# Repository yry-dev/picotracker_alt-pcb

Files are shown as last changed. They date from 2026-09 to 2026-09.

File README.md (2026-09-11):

# Picotracker Alt-PCB

~~**Do not fabricate! There could be a major mistake around MIDI!!**~~

**[Alex fixed it!](https://github.com/ijnekenamay/picotracker_alt-pcb/pull/2) We should be able to go ahead with production now.**

This project is about [democloid picoTracker's](https://github.com/democloid/picoTracker/) alternative PCB.
Inexpensive handheld devices can be built to run LittleGPTracker(a.k.a piggytracker).
It basically follows the original DIY version, with a few modifications of my own. They are described below.

[You can see it in motion here.](https://www.instagram.com/p/C2BvngaruZN/?utm_source=ig_web_copy_link&igsh=MzRlODBiNWFlZA==)



## Feature

- The two PCBs act as an enclosure by sandwiching the components together.
- I wanted a module for the charging function and plenty of memory, so I went with the [Pimoroni Pico LiPo](https://shop.pimoroni.com/products/pimoroni-pico-lipo).
- I wanted a micro-speaker like the DirtywaveM8, so I added one... and a Class D amplifier module.
- A speaker kill switch has been added.
- This also uses Kailh Choc V1 for the keycaps because of my personal taste.
- You can change any specification by yourself if you have access to Kicad.
- [See image for values of components around MIDI.](https://raw.githubusercontent.com/ijnekenamay/picotracker_alt-pcb/main/images/MIDI_resistor_value.jpg)
- I designed a back panel that could be output with a 3D printer because I felt the microspeaker needed box resonance. Also, if you would like to try it, please see the STL data. Feedback is welcome.
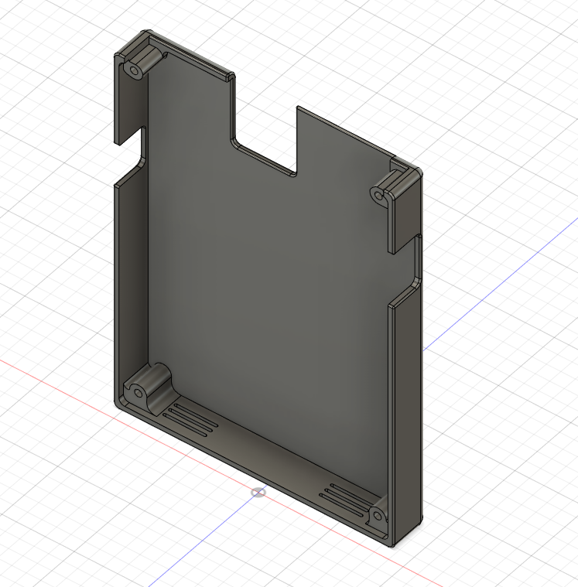
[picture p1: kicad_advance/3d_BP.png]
- 

## BOM

| Value | Qty | Avg unit price¹ | Mouser | DigiKey | Notes |
| --- | --- | --- | --- | --- | --- |
| Pimoroni Pico LiPo 16MB | 1 | ~$8–16 | — | — | [Pimoroni](https://shop.pimoroni.com/products/pimoroni-pico-lipo) (~$15.95, [PiShop US](https://www.pishop.us/product/pimoroni-pico-lipo-16mb/)) · [JP](https://akizukidenshi.com/catalog/g/g116997/). Equivalent: [Waveshare RP2040-Plus 16MB](https://www.amazon.com/Waveshare-RP2040-Plus-High-Performance-Microcontroller-Compatible/dp/B09KZKKWJT) ([Waveshare](https://www.waveshare.com/rp2040-plus.htm)), ~$8 — Pico-pinout, USB-C, onboard LiPo charge, 16MB (use the **no-header/castellated** version). |
| ILI9341 3.2" display | 1 | ~$12–18 | — | — | [AliExpress](https://www.aliexpress.us/item/3256802819098352.html). Equivalents: generic 3.2" ILI9341 SPI 320×240 on [Amazon](https://www.amazon.com/ALMOCN-ILI9341-Display-320x240-Screen/dp/B0C88S6FK7) (ALMOCN/Hosyond/ACEIRMC, ~$15) — **verify the 8-pin SPI header order matches J7**. Tayda has only a [2.8" ILI9341](https://www.taydaelectronics.com/2-8-inch-spi-display-screen-tft-with-touch-ili9341.html) (smaller). Mouser/DigiKey carry ILI9341 breakouts (Adafruit/Newhaven) but with different pinouts — **not drop-in**. |
| GY-PCM5102 DAC module | 1 | — | — | — | [AliExpress](https://www.aliexpress.us/item/3256802711963831.html) |
| Adafruit Micro SD SPI/SDIO Breakout | 1 | — | — | — | [Adafruit](https://www.adafruit.com/product/4682) |
| Kailh Choc V1 key switch | 9 | — | — | — | specialty (mechanical-keyboard vendors) |
| keycaps (Kailh Choc) | 9 | — | — | — | specialty |
| MAX98306 class-D amp module | 1 | — | — | — | [AliExpress](https://ja.aliexpress.com/item/1005004990814956.html) (Adafruit #987) |
| Micro speaker | 2 | — | — | — | [Akizuki](https://akizukidenshi.com/catalog/g/gP-12494/) |
| DPDT slide switch (through-hole) | 1 | ~$0.84 | [JS202011AQN](https://www.mouser.com/c/?q=JS202011AQN) | [JS202011AQN](https://www.digikey.com/en/products/detail/c-k/JS202011AQN/1640096) | J9 (KILL_SWITCH); C&K JS202011AQN, right-angle. Generic SS-22 / MSK22D18G2 (LCSC C2906279, ~$0.07) also fits. GND on center pins. |
| PJ-311 3.5mm stereo jack | 2 | varies | — | — | MIDI in/out (J1, J2). Generic PJ-311/PJ-320 import — no footprint-compatible Mouser/DigiKey catalog part. |
| 1N4148 | 1 | ~$0.10 | [1N4148](https://www.mouser.com/c/?q=1N4148) | [1N4148](https://www.digikey.com/en/products/result?keywords=1N4148) | D1; DO-35 axial |
| 47R | 2 | ~$0.11 | [CFR-25JB-52-47R](https://www.mouser.com/c/?q=CFR-25JB-52-47R) | [CFR-25JB-52-47R](https://www.digikey.com/en/products/result?keywords=CFR-25JB-52-47R) | axial 1/4W (DIN0207, 7.62mm) |
| 220R | 1 | ~$0.10 | [CFR-25JB-52-220R](https://www.mouser.com/c/?q=CFR-25JB-52-220R) | [CFR-25JB-52-220R](https://www.digikey.com/en/products/result?keywords=CFR-25JB-52-220R) | axial 1/4W (DIN0207, 7.62mm) |
| 470R | 1 | ~$0.11 | [CFR-25JB-52-470R](https://www.mouser.com/c/?q=CFR-25JB-52-470R) | [CFR-25JB-52-470R](https://www.digikey.com/en/products/result?keywords=CFR-25JB-52-470R) | axial 1/4W (DIN0207, 7.62mm) |
| 10k | 1 | ~$0.10 | [CFR-25JB-52-10K](https://www.mouser.com/c/?q=CFR-25JB-52-10K) | [CFR-25JB-52-10K](https://www.digikey.com/en/products/result?keywords=CFR-25JB-52-10K) | axial 1/4W (DIN0207, 7.62mm) |
| 6N138 | 1 | ~$0.83 | [6N138](https://www.mouser.com/c/?q=6N138) | [6N138](https://www.digikey.com/en/products/result?keywords=6N138) | U2; DIP-8 optocoupler |
| LiPo battery | 1 | — | — | — | 1200mAh (author's choice) — hobby battery vendors |
| Pin headers / standoffs / screws / nuts | * | — | [headers](https://www.mouser.com/c/?q=2.54mm+pin+header) | [headers](https://www.digikey.com/en/products/result?keywords=2.54mm+pin+header) | See note below on short headers vs sockets |

¹ **Avg unit price** — indicative qty-1 price in USD, from Mouser (the DPDT switch is averaged with DigiKey). Modules are priced at their linked vendors (they aren't stocked by Mouser/DigiKey). Most distributor cells are keyword/site searches — pick the exact package/stock on the results page; the DPDT switch uses direct product links (Mouser and DigiKey). Stock and prices change, so confirm at the link before ordering.

It is recommended to use short pin headers and to solder directly without using sockets. At the very least, the effective depth of the 3D printer back panel is only 11 mm, which would interfere with the use of pin sockets. (but i wanted to go thin)

The images below are prototype versions and differ from the actual data.



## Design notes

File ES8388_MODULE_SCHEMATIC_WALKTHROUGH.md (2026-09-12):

# ES8388 Module — Hand-drawing the schematic in KiCad

A step-by-step, follow-along guide to draw the codec module schematic yourself in Eeschema
(KiCad 9/10). Values and connections come from `ES8388_MODULE_PLAN.md` (which was verified against
the mainboard netlist). Work top-to-bottom; there are **checkpoints** where you can stop and sanity-check.

## Eeschema hotkeys you'll use constantly
| Key | Action |
|---|---|
| `A` | Add symbol |
| `P` | Add **power** symbol (GND, +3V3, PWR_FLAG) |
| `W` | Draw wire |
| `L` | Place **net label** (names a wire) |
| `M` / `G` | Move / drag (G keeps wires attached) |
| `R` | Rotate |
| `C` | Duplicate (copy) the hovered item |
| `E` | Edit properties/value |
| `Q` | Place **no-connect** (×) flag on unused pins |
| `Del` | Delete |
| `Ctrl+S` | Save |

Tip: you almost never need long wires. Put a short stub on a pin and give it a **label** (`L`);
two stubs with the same label are the same net. We'll use that heavily.

---

## Phase 0 — Get the ES8388 symbol + footprint

KiCad has no built-in ES8388. Easiest path that also guarantees the footprint matches the JLC part
(LCSC **C365736**) you'll assemble:

```bash
pip install easyeda2kicad
easyeda2kicad --full --lcsc_id=C365736 --output ~/kicad-libs/es8388
```

This produces `es8388.kicad_sym`, an `es8388.pretty/` footprint folder, and a 3D model.

In KiCad: **Preferences → Manage Symbol Libraries → Project Specific Libraries → +**, add
`~/kicad-libs/es8388.kicad_sym`. Do the same under **Manage Footprint Libraries** for the `.pretty`.

The two pin headers need no import — they use stock KiCad symbols/footprints (Phase 6).

> Alternative if you'd rather not use easyeda2kicad: make a symbol by hand in the Symbol Editor —
> a 28-pin rectangle + EP pin, names exactly as in the pin table below. Slower; the importer is worth it.

**Checkpoint 0:** you can type `A`, search "ES8388", and place the symbol.

### Parts list — set each symbol's Value + LCSC as you place it
All JLCPCB **Basic/Preferred** (no assembly fee) except the ES8388. In KiCad you can stuff the LCSC
code into a field named `LCSC` (or `JLCPCB`) on each symbol so the assembly BOM is ready later.

| Value / part | Qty | Pkg | LCSC | Use |
|---|---|---|---|---|
| ES8388 | 1 | QFN‑28‑EP 4×4 | **C365736** | codec (U1) |
| 100 nF X7R 16V | ~8 | 0402 | **C1525** | every 0.1 µF decoupling |
| 1 µF X5R 25V | 5 | 0402 | **C52923** | input coupling (LINE_L/R, MIC) + aux line-out (LOUT2/ROUT2) |
| 4.7 µF X5R 16V | 4 | 0603 | **C19666** | DVDD + VREF/VMID/ADCVREF |
| 10 µF X5R 10V | 2 | 0603 | **C19702** | +3V3 / +3V3A bulk |
| 100 µF X5R 6.3V | 4 | 1206 | **C15008** | HPVDD **2× parallel** + 2× HP DC‑block |
| 30 pF C0G 50V | 1 | 0402 | **C1570** | optional MCLK edge cap |
| 2.2 nF X7R 50V | 1 | 0402 | **C1531** | optional I²C‑clock RC |
| 33 Ω | 5 | 0402 | **C25105** | digital series damping |
| 22 Ω | 2 | 0402 | **C25092** | LOUT1/ROUT1 series |
| 10 Ω | 1 | 0402 | **C25077** | AVDD↔HPVDD |
| 0 Ω | 1 | 0402 | **C17168** | CE→GND (addr 0x20) |
| 5.1 kΩ | 2 | 0402 | **C25905** | I²C pull‑ups (4.7 kΩ alt = C23162, 0603) |
| 330 Ω | 1 | 0402 | **C25104** | optional I²C‑clock series |
| Ferrite 600 Ω@100 MHz | 1 | 0603 | **C1002** | FB1 analog‑rail filter |
| 1×9 male header 2.54 mm | 1 | THT | — | J1 (mates J11) |
| 1×6 male header 2.54 mm | 1 | THT | — | J2 (mates J12) |
| 1×3 male header 2.54 mm | 1 | THT | — | J3 aux line-out (LOUT2/ROUT2/GND) |

---

## Phase 1 — New project

1. **File → New Project** → name it `kicad_es8388_module`, save it in the repo root next to
   `kicad_advance/`.
2. Open the `.kicad_sch`. You'll be on one sheet — the whole module fits on one page.
3. Suggested canvas zones (just so it stays readable):
   - **Left:** power in + supply/decoupling network
   - **Center:** the ES8388
   - **Upper-right:** digital header `J1` + series resistors + I²C
   - **Lower-right:** analog header `J2` + coupling caps

---

## Phase 2 — Place the ES8388 and the ground/power symbols

1. `A` → search **ES8388** → place it in the center.
2. `E` on it → set **Reference = U1**.
3. `P` → place a **GND** symbol somewhere central (you'll copy it around with `C`).
4. `P` → place a **+3V3** symbol (this is our digital rail = header VCC).
5. `P` → place a second power symbol, `E` its value to **+3V3A** (analog rail; we'll make it from
   +3V3 through a ferrite bead). If +3V3A isn't offered, use a generic power symbol and rename it.

Here is the ES8388 pin reference you'll wire against (QFN-28 + EP):

| Pin | Name | Pin | Name |
|----:|---|----:|---|
| 1 | MCLK | 15 | LOUT2 |
| 2 | DVDD | 16 | HPVDD |
| 3 | PVDD | 17 | AVDD |
| 4 | DGND | 18 | AGND |
| 5 | SCLK | 19 | ADCVREF |
| 6 | DSDIN | 20 | VMID |
| 7 | LRCK | 21 | RIN2 |
| 8 | ASDOUT | 22 | LIN2 |
| 9 | NC | 23 | RIN1 |
| 10 | VREF | 24 | LIN1 |
| 11 | ROUT1 | 25 | NC |
| 12 | LOUT1 | 26 | CE |
| 13 | HPGND | 27 | CDATA |
| 14 | ROUT2 | 28 | CCLK |
| | | 29 | EP (GND) |

**Checkpoint 2:** U1 placed, one each of GND / +3V3 / +3V3A power symbols on the sheet.

---

## Phase 3 — Power & decoupling network (left zone)

We split the 3.3 V into a clean analog rail. All caps go from the pin to **GND**.

**Rail generation:**
1. Place an **inductor/ferrite** symbol (`A` → `FerriteBead` or `Device:L`), Ref **FB1**, value e.g.
   `600R@100MHz`. Wire **+3V3 → FB1 → +3V3A**.
2. Place a **10 Ω** resistor `R1`. Wire **+3V3A → R1 → HPVDD (pin 16)**. (App-note isolation between
   AVDD and HPVDD.)

**Decoupling (place cap, `E` to set value, wire pin→cap→GND):**

**Supply pins** — wire to the rail **and** add the caps to GND:

| Codec pin | Wire to rail | Caps to GND |
|---|---|---|
| DVDD (2) | +3V3 | 4.7 µF ∥ 0.1 µF |
| PVDD (3) | +3V3 | 0.1 µF |
| AVDD (17) | +3V3A | 0.1 µF |
| HPVDD (16) | +3V3A via 10 Ω | **2× 100 µF** ∥ 0.1 µF (parallel — offsets 6.3 V MLCC DC-bias derating) |

**Reference pins** — these are voltages the chip generates *internally*. **Do NOT wire them to any
rail.** The only connection is a decoupling cap to GND (a smoothing tank on an internal bias voltage):

| Codec pin | Wire to rail | Caps to GND |
|---|---|---|
| VREF (10) | none — internal output | 4.7 µF ∥ 0.1 µF |
| VMID (20) | none — internal output | 4.7 µF ∥ 0.1 µF |
| ADCVREF (19) | none — internal output | 4.7 µF ∥ 0.1 µF |

**Grounds:** wire **DGND(4), AGND(18), HPGND(13), and EP(29)** all to **GND** symbols. (On the module,
one GND net is correct — the module is the single AGND↔GND star point; the analog/digital split is a
layout concern later, not a schematic-net concern.)

Reference designator tip: don't hand-number caps — you'll run **Tools → Annotate** at the end and KiCad
assigns C1, C2, … automatically. Just place them with the right values.

**Checkpoint 3:** every power pin (2,3,16,17) has decoupling; the three bias pins (10,19,20) have their
4.7 µF∥0.1 µF; all grounds tied. This is the fiddliest phase — take your time.

---

## Phase 4 — Digital header J1 + series resistors + I²C (upper-right)

1. Place the digital header last (Phase 6) or now — either works. For now, wire the codec side using
   **labels** so you don't need the header physically yet.

**Series-damping resistors (33 Ω each).** For each line: put a resistor, wire the codec pin to one
end, and put a **label** (`L`) on the *other* end with the header-facing net name:

| Codec pin | Series R | Label on far end |
|---|---|---|
| MCLK (1) | 33 Ω | `MCLK` |
| SCLK (5) | 33 Ω | `BCK` |
| LRCK (7) | 33 Ω | `LRCK` |
| DSDIN (6) | 33 Ω | `DIN` |
| ASDOUT (8) | 33 Ω | `I2S_SDIN` |

(Optional: a 30 pF cap from the **codec side** of the MCLK resistor to GND.)

**I²C:**
1. CDATA (27): wire a stub, label it `SDA`.
2. CCLK (28): optional 330 Ω series toward the header; label the header side `SCL`. (Optional 2.2 nF
   from the CCLK pin to GND for the app-note RC filter.)
3. **Pull-ups (populate these — the mainboard has none):** two **5.1 kΩ** resistors (C25905 — the
   Basic 0402 value; 4.7 kΩ isn't Basic in 0402), each from `SDA` and `SCL` up to **+3V3**. Put them
   on the header side of any series R.

**CE / I²C address (pin 26):**
- Place a **0 Ω** resistor `R?` from **CE (26) → GND** → address **0x20** (default).
- Optionally add a second pad/resistor from CE → +3V3 (leave unpopulated) for **0x22**. Never wire CE
  to a GPIO.

**NC pins:** press `Q` on pins **9** and **25** to drop no-connect flags.

**Checkpoint 4:** the 5 digital lines each go codec → 33 Ω → labeled net; SDA/SCL labeled with 5.1 kΩ
pull-ups to +3V3; CE has its 0 Ω to GND; NC flags on 9 & 25.

---

## Phase 5 — Analog inputs & outputs + coupling (lower-right)

All analog signals are AC-coupled. Use **labels** for the header-facing nets again.

**Inputs (label → coupling cap → codec pin):**

| Header net (label) | Coupling | Codec pin |
|---|---|---|
| `LINE_L` | 1 µF | LIN2 (22) |
| `LINE_R` | 1 µF | RIN2 (21) |
| `MIC_IN` | 1 µF | LIN1 (24) |

- The mic is mono → tie the unused **RIN1 (23)** to **GND** (or via 0.1 µF); it's disabled in registers.

**Outputs (codec pin → 22 Ω → DC-block 100 µF → label). Electrolytic polarity: `+` toward the codec
(VMID-biased) side:**

| Codec pin | Series | DC-block (+ to codec) | Header net (label) |
|---|---|---|---|
| LOUT1 (12) | 22 Ω | 100 µF | `L_AMP` |
| ROUT1 (11) | 22 Ω | 100 µF | `R_AMP` |

**Aux line-out (LOUT2/ROUT2)** — broken out on a separate header so the module is reusable outside
the picoTracker. Codec pin → 1 µF (line-level coupling) → aux label:

| Codec pin | Coupling | Aux label |
|---|---|---|
| LOUT2 (15) | 1 µF | `LINEOUT_L` |
| ROUT2 (14) | 1 µF | `LINEOUT_R` |

- Place **J3** = `Conn_01x03`: pin 1 `LINEOUT_L`, pin 2 `LINEOUT_R`, pin 3 `GND`.
  Footprint later = `PinHeader_1x03_P2.54mm_Vertical`. J3 is unused when mated to the picoTracker.
- (Optional: add a 22 Ω series on each like the main outputs — app-note style. Not required for a
  high-impedance line load.)

**Now only pins 9 & 25 are no-connects** (LOUT2/ROUT2 are used) — leave the `Q` flags on 9 & 25 only.

**Checkpoint 5:** three inputs coupled in (RIN1 grounded); two main outputs (LOUT1/ROUT1) via 22 Ω +
100 µF to L_AMP/R_AMP; two aux line-outs (LOUT2/ROUT2) via 1 µF to J3; only pins 9 & 25 no-connected.

---

## Phase 6 — The headers (the mating interface + aux)

1. `A` → **Conn_01x09** → place as **J1** (digital). `A` → **Conn_01x06** → place as **J2** (analog).
   `A` → **Conn_01x03** → place as **J3** (aux line-out).
2. Wire each header pin to a short stub and `L` a label matching the tables below. Same label name =
   connected to the matching net you already drew — that's how the header ties into the codec side.

**J1 (digital, 1×9):**
```
1 +3V3   2 GND   3 MCLK   4 BCK   5 LRCK   6 DIN   7 I2S_SDIN   8 SDA   9 SCL
```
**J2 (analog, 1×6):**
```
1 LINE_L   2 LINE_R   3 MIC_IN   4 L_AMP   5 R_AMP   6 AGND
```
**J3 (aux line-out, 1×3 — not part of the picoTracker mate):**
```
1 LINEOUT_L   2 LINEOUT_R   3 GND
```

- For J2 pin 6, label it `AGND` **but** also connect module GND here — simplest is to just label it
  `GND` so it merges into the module ground (the module is the star point). If you prefer to keep the
  name, label it `AGND` and drop a short wire joining `AGND` to a `GND` symbol once, near U1's EP.

> ⚠️ The **pin order above is fixed** — it's what the mainboard's J11/J12 expect. Physical 5.70 mm
> spacing between the two headers is set in the PCB layout step, not here.

**Checkpoint 6:** J1 has 9 labeled pins, J2 has 6, J3 has 3 (LINEOUT_L/R + GND), every label name
matches one already used on the codec side.

---

## Phase 7 — Footprints, ERC, and finish

1. **PWR_FLAG:** `P` → place **PWR_FLAG** and attach one to **+3V3** and one to **GND** (power enters
   from a connector, so ERC needs these or it complains about "no driving source"). Optionally one on
   +3V3A too.
2. **Tools → Annotate Schematic** → fills in R/C/etc. reference numbers.
3. **Assign footprints** (Tools → Assign Footprints, or the property on each symbol):
   - U1 → the imported `es8388` footprint (QFN-28-EP 4×4).
   - J1 → `Connector_PinHeader_2.54mm:PinHeader_1x09_P2.54mm_Vertical`
   - J2 → `Connector_PinHeader_2.54mm:PinHeader_1x06_P2.54mm_Vertical`
   - J3 → `Connector_PinHeader_2.54mm:PinHeader_1x03_P2.54mm_Vertical`
     (these are the exact footprints the mainboard uses — guarantees the mate.)
   - Passives → the packages in the parts list (0402 small, 0603 for 4.7/10 µF, **1206** for the
     100 µF C15008 MLCCs).
4. **Inspect → Electrical Rules Checker → Run.** Resolve:
   - Unconnected pins → add `Q` no-connects (NC pins 9, 25 only — LOUT2/ROUT2 now go to J3).
   - "No driving source" on power → add the PWR_FLAGs from step 1.
5. `Ctrl+S`.

**Done.** Next you'd do **Tools → Update PCB from Schematic** and start the layout (that's where the
5.70 mm header spacing, ground pours, and the AGND↔GND EP star point get placed).

---

## Quick full connection recap (for wiring without scrolling)

```
POWER
 +3V3 (=VCC, J1.1) ── DVDD(2)[4.7u+0.1u]  ── PVDD(3)[0.1u]  ── 5.1k pull-ups(SDA,SCL)
 +3V3 ──FB1── +3V3A ── AVDD(17)[0.1u]
 +3V3A ──10R── HPVDD(16)[2×100u+0.1u]
 GND ── DGND(4), AGND(18), HPGND(13), EP(29), J1.2, J2.6
 VREF(10)[4.7u+0.1u]  VMID(20)[4.7u+0.1u]  ADCVREF(19)[4.7u+0.1u]

DIGITAL (each via 33R)         I2C
 MCLK  ─33R─ MCLK(1)            SDA ── CDATA(27), 5.1k→+3V3
 BCK   ─33R─ SCLK(5)            SCL ─(330R opt)─ CCLK(28), 5.1k→+3V3, 2.2n→GND opt
 LRCK  ─33R─ LRCK(7)            CE(26) ─0R─ GND   (addr 0x20)
 DIN   ─33R─ DSDIN(6)           NC: pins 9, 25 → no-connect
 I2S_SDIN ─33R─ ASDOUT(8)

ANALOG
 LINE_L ─1u─ LIN2(22)           LOUT1(12) ─22R─100u(+ to codec)─ L_AMP
 LINE_R ─1u─ RIN2(21)           ROUT1(11) ─22R─100u(+ to codec)─ R_AMP
 MIC_IN ─1u─ LIN1(24)           LOUT2(15) ─1u─ LINEOUT_L (J3.1)
 RIN1(23) → GND (mic mono)      ROUT2(14) ─1u─ LINEOUT_R (J3.2)
                                NC: pins 9, 25 only
```

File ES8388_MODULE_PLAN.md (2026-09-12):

# ES8388 Codec Module — Design Plan

A small daughterboard that carries the **ES8388** SMD audio codec (QFN‑28) plus all its
support passives, and plugs directly into the two codec headers already on the
picoTracker Advance mainboard (`J11 CODEC_DIG`, `J12 CODEC_ANA`). This keeps the fine‑pitch
QFN and sensitive analog network off the hand‑assembled mainboard and turns the codec into a
solder‑and‑go module, exactly like the reference board in `~/Desktop/example.png`.

> **Sources for this plan**
> - ES8388 User Guide / App Note (pcbartists.com) — §3 Typical Application Circuit, §2 operating
>   conditions, §4 I²C addressing, §5 digital audio interface, layout notes.
> - `~/Desktop/example.png` — a community ES8388 breakout (2×10 headers) — used for the
>   physical concept only; **our pinout is different** (it must match our mainboard).
> - The Advance mainboard itself: header pinouts and analog net destinations were read
>   directly from `kicad_advance/pico_tracker.kicad_sch` / `.kicad_pcb`.

---

## 1. Goal & constraints

| Requirement | Decision |
|---|---|
| Must plug into existing `J11`/`J12` with **no mainboard changes** | Module carries two **male** pin headers matching J11 (9‑pin) and J12 (6‑pin) exactly |
| Match the mainboard's net names/order | Pinouts frozen below, read from the schematic |
| Codec supply | Header `VCC` = Pico **3.3 V** rail (confirmed: Pico 2 `3V3` net). Digital runs off it; analog is **ferrite‑bead‑isolated 3.3 V** on‑module (no LDO — can't regulate 3.3→3.3) |
| Assembly | ES8388 + 0402/0603 passives are JLCPCB‑assembled on the module; mainboard stays simple |
| Cost/availability | ES8388 = LCSC **C365736**, ~$1.10, 14k–24k stock (chosen over TLV320AIC3204: cheaper + far more common) |

---

## 2. Mating interface (frozen — this is the whole point of the module)

Read from `kicad_advance/pico_tracker.kicad_pcb`. Both headers are single‑row **2.54 mm** pitch,
pins running in +Y, sitting side‑by‑side:

- `J11 CODEC_DIG` — 9 pins, column at **X = 104.80**, pin 1 at **Y = 91.84**
- `J12 CODEC_ANA` — 6 pins, column at **X = 110.50**, pin 1 at **Y = 91.65**
- **Inter‑column spacing ΔX = 5.70 mm**, pin‑1 rows aligned within 0.19 mm.

> ⚠️ 5.70 mm is *not* an integer 2.54 multiple, so **do not eyeball it**. The safe path:
> import the exact `J11`/`J12` footprints/positions from the mainboard PCB into the module so
> the geometry is guaranteed identical, then populate male headers.

### J11 `CODEC_DIG` — digital (9‑pin)
Pico GPIO confirmed from the exported netlist (`U1` = Pico 2):

| Pin | Mainboard net | Pico GPIO | ES8388 pin | Notes |
|----:|---|---|---|---|
| 1 | **VCC** (3.3 V) | Pico `3V3` | DVDD/PVDD feed | digital supply in |
| 2 | **GND** | — | DGND | |
| 3 | **MCLK** | **GP28** | MCLK (1) | PIO 256·fs |
| 4 | **BCK** | **GP18** | SCLK (5) | I²S bit clock |
| 5 | **LRCK** | **GP19** | LRCK (7) | I²S word clock |
| 6 | **DIN** | **GP17** | DSDIN (6) | DAC data, Pico → codec |
| 7 | **I2S_SDIN** | **GP16** | ASDOUT (8) | ADC data, codec → Pico |
| 8 | **SDA** | **GP14** | CDATA (27) | I²C data |
| 9 | **SCL** | **GP15** | CCLK (28) | I²C clock |

### J12 `CODEC_ANA` — analog (6‑pin)
Destinations verified from the mainboard (which jack/amp each net actually reaches):

| Pin | Mainboard net | Goes to on mainboard | ES8388 side |
|----:|---|---|---|
| 1 | **LINE_L** | `J13 LINE_IN` jack (input) | → **LIN2 (22)** line input |
| 2 | **LINE_R** | `J13 LINE_IN` jack (input) | → **RIN2 (21)** line input |
| 3 | **MIC_IN** | `J15 MIC_MODULE` (electret) | → **LIN1/RIN1 (24/23)** mic input |
| 4 | **L_AMP** | `J14 PHONES` jack **and** `J10 DclassAMP` | ← **LOUT1 (12)** output |
| 5 | **R_AMP** | `J14 PHONES` jack **and** `J10 DclassAMP` | ← **ROUT1 (11)** output |
| 6 | **AGND** | analog ground | AGND/HPGND |

Key takeaways that drive the circuit:
- **LINE_L/LINE_R are codec *inputs*** (from the line‑in jack), not outputs.
- **L_AMP/R_AMP are codec *outputs*** feeding both the headphone jack and the class‑D
  speaker amp — so they need real drive capability → use the **HP driver LOUT1/ROUT1**.
- **MIC_IN is a single‑ended** mic signal from the existing mic module.

---

## 3. Power architecture

Header gives us one 3.3 V rail + ground. Split on‑module into clean digital/analog:

```
VCC(3.3V) ─┬─ DVDD (pin2)  ── 4.7µF ∥ 0.1µF ──GND
           ├─ PVDD (pin3)  ── 0.1µF ──GND        (I²C buffer supply)
           └─[FB ferrite]─┬─ AVDD  (pin17) ── 0.1µF ──GND
              +10µF bulk   ├─[10Ω]─ HPVDD (pin16) ── 2×100µF ∥ 0.1µF ──GND
                           └─ analog 3.3V_A reference island
```

- App note recommends a dedicated LDO for the analog side; since our header only exposes
  3.3 V we instead use a **ferrite bead + bulk cap** LC filter (standard for these modules).
- **10 Ω between AVDD and HPVDD** (app‑note recommended when they share a rail).
- One solid **AGND pour**; single‑point tie to DGND under the QFN EP.

*(If a future mainboard rev exposes 5 V on the header, an LM1117‑3.3 per the app note's typical
circuit would give marginally lower noise — noted as optional, not required.)*

---

## 4. Codec support circuit (values from the app‑note Typical Application Circuit)

**Reference / bias caps (all to GND, close to the pin):**
| Pin | Net | Cap |
|---|---|---|
| 10 | VREF | 4.7µF ∥ 0.1µF |
| 20 | VMID | 4.7µF ∥ 0.1µF |
| 19 | ADCVREF | 4.7µF ∥ 0.1µF |
| 16 | HPVDD | **2× 100µF** ∥ 0.1µF |
| 17 | AVDD | 0.1µF |
| 2 | DVDD | 4.7µF ∥ 0.1µF (behind ferrite from VCC) |
| 3 | PVDD | 0.1µF |

**Digital lines — series damping resistors on every clock/data line (app note uses 33 Ω;
22 Ω also fine):**
- MCLK(1), SCLK(5), DSDIN(6), LRCK(7), ASDOUT(8): **33 Ω series** each.
- MCLK optionally **30 pF to GND** for edge rate.

**I²C (CCLK/CDATA, pins 28/27):**
- **Pull‑ups to 3.3 V on both — POPULATE them on the module.** Netlist trace shows the
  **mainboard has *no* I²C pull‑ups** (SCL/SDA only reach Pico GP15/GP14, codec J11, and the
  fuel‑gauge J16 — no resistors). The bus needs pull‑ups and the codec module is the right owner.
- Use **4.7 kΩ** (not the app note's 1 kΩ) so that *if* the MAX17048 fuel‑gauge module also carries
  pull‑ups, the parallel value stays sane. Put them on a solder‑jumper so they can be lifted.
- App‑note **R‑C low‑pass on the clock**: 330 Ω series + ~2.2 nF to GND (optional; improves noise).

**CE / I²C address (pin 26):**
- **0 Ω to DGND → address `0x20`** (default). Pull‑up option pad to PVDD → `0x22`.
- Expose as a solder‑jumper so firmware address is selectable. **Never** wire CE to a GPIO.

**Analog I/O coupling:**
| Path | Pins | Coupling |
|---|---|---|
| Line‑out (to L_AMP/R_AMP → phones + amp) | LOUT1(12)/ROUT1(11) | 22 Ω series + **100 µF** DC‑block (elec.), + ~330 Ω bleed |
| Line‑in (from LINE_L/LINE_R jack) | LIN2(22)/RIN2(21) | 1 µF series AC‑couple + 0.1µF/47µF filter per app note |
| Mic‑in (from MIC_IN) | LIN1(24)/RIN1(23) | 1 µF AC‑couple; single‑ended (tie unused input to VMID via 0.1µF) |

> **DC‑block placement — RESOLVED (was Open Q1):** netlist confirms `L_AMP` = {J12.4, J14.T
> (phones), J10.4 (amp)} and `R_AMP` = {J12.5, J14.R, J10.7} are **bare 3‑node nets with zero
> series components** on the mainboard. The ES8388 HP outputs are VMID‑biased, so the **module
> must provide the series DC‑block caps** (100 µF). Confirmed as plan of record.

---

## 5. Bill of materials (module)

| Value / part | Qty | Pkg | LCSC | Lib | Use |
|---|---|---|---|---|---|
| ES8388 | 1 | QFN‑28‑EP 4×4 | **C365736** | Extended | codec |
| 100 nF X7R 16V | ~8 | 0402 | **C1525** | Basic | all 0.1µF decoupling |
| 1 µF X5R 25V | 5 | 0402 | **C52923** | Basic | input coupling (LINE_L/R, MIC) + aux line-out (LOUT2/ROUT2) |
| 4.7 µF X5R 16V | 4 | 0603 | **C19666** | Basic | DVDD + VREF/VMID/ADCVREF |
| 10 µF X5R 10V | 2 | 0603 | **C19702** | Basic | +3V3 / +3V3A bulk |
| 100 µF X5R 6.3V | 4 | 1206 | **C15008** | Basic | **HPVDD 2× parallel** + 2× HP DC‑block |
| 30 pF C0G 50V | 1 | 0402 | **C1570** | Preferred | optional MCLK edge cap |
| 2.2 nF X7R 50V | 1 | 0402 | **C1531** | Preferred | optional I²C‑clock RC |
| 33 Ω 1% | 5 | 0402 | **C25105** | Basic | digital series damping |
| 22 Ω 1% | 2 | 0402 | **C25092** | Basic | LOUT1/ROUT1 series |
| 10 Ω 1% | 1 | 0402 | **C25077** | Basic | AVDD↔HPVDD isolation |
| 0 Ω jumper | 1 | 0402 | **C17168** | Basic | CE→GND (I²C addr 0x20) |
| 5.1 kΩ 1% | 2 | 0402 | **C25905** | Basic | I²C pull‑ups (4.7 kΩ alt = C23162, 0603) |
| 330 Ω 1% | 1 | 0402 | **C25104** | Basic | optional I²C‑clock series |
| Ferrite 600 Ω@100 MHz, 200 mA | 1 | 0603 | **C1002** | Basic | FB1 analog‑rail filter |
| 1×9 male header 2.54 mm | 1 | THT | — | — | J1, mates mainboard J11 |
| 1×6 male header 2.54 mm | 1 | THT | — | — | J2, mates mainboard J12 |
| 1×3 male header 2.54 mm | 1 | THT | — | — | J3, aux stereo line-out (LOUT2/ROUT2/GND); unused on picoTracker |

All passives are JLCPCB **Basic/Preferred** (no assembly fee); only the ES8388 is Extended (one +$3
fee). Headers are through‑hole — usually hand‑soldered (THT assembly adds cost). The 0.1 µF count is
approximate — one per decoupled pin; annotate in KiCad to get the exact number.

> **Why 2× 100 µF on HPVDD:** C15008 is a 6.3 V X5R MLCC and loses a large fraction of its rated
> capacitance under DC bias — at 3.3 V it behaves like roughly half its face value. Two in parallel
> restores an effective ~100 µF of bulk on the headphone supply. (The two HP‑output DC‑block 100 µF
> caps sit at low DC bias, so a single each is fine.)

---

## 6. PCB & mechanical

- **2‑layer**, ~**25 × 22 mm** (fits QFN + passives + two header columns; comparable to the
  example board). Top: QFN + digital passives; keep analog passives clustered by the analog pins.
- **Header placement:** J1/J2 at the imported mainboard coordinates (ΔX = 5.70 mm, pin‑1 aligned).
  Headers along one edge so the module stands over the mainboard like the example.
- **Orientation / pin‑1:** module is a plug‑in daughterboard — its pad (i) must sit directly over
  mainboard socket (i). Import footprints, then **verify pin‑1 dots line up** in a 3D/overlay check
  before ordering (classic mirror‑flip bug).
- **Grounding — the module is the star point (netlist‑confirmed):** on the mainboard `AGND` and
  `GND` are **separate nets**. `AGND` = {J12.6 codec, J13/J14 jack sleeves, J10.5/6 amp}; `GND` =
  {J11.2 codec, Pico, SD, mic, fuel gauge, …}. The codec module receives *both* (GND on J11.2,
  AGND on J12.6) and is the natural place to **tie AGND↔GND at the QFN EP thermal pad** (single
  star point). Continuous AGND pour under the analog section, DGND under the digital section,
  joined only at the EP; EP stitched down with a via array.
- ⚠️ **Ground‑loop watch:** the class‑D amp module (`J10`) is the *only other* connector touching
  both AGND (5,6) and GND (2), so it may also bridge them internally → a potential loop with the
  codec module's star tie. Prefer the codec EP as the single tie; if the amp module hard‑ties them
  too, that's an acceptable‑but‑noted second bridge (class‑D input is not sensitive).
- **Layout notes from app note:** decoupling caps hard against their pins; if a future differential
  mic is used, route MIC_INP/MIC_INN as a parallel pair. Keep MCLK away from analog traces.
- Silkscreen: label both headers with net names + pin 1, and mark the CE address jumper
  (`0x20` default) and the DNP I²C pull‑ups.

---

## 7. Open questions — RESOLVED by netlist trace

Traced against the KiCad‑exported netlist of `kicad_advance/pico_tracker.kicad_sch`. Results:

1. **HP output DC‑block → module provides it.** `L_AMP`/`R_AMP` are bare nets, codec → phones jack →
   amp, no series parts. Module carries the 100 µF DC‑block caps. ✅ resolved.
2. **I²C pull‑ups → module provides them.** Mainboard has **no** SCL/SDA pull‑ups anywhere. Populate
   4.7 kΩ pull‑ups on the module (jumpered). ✅ resolved. *(Only residual check: whether the plug‑in
   MAX17048 fuel‑gauge module carries its own pull‑ups — if so they parallel the module's; harmless
   at 4.7 kΩ.)*
3. **MCLK → confirmed GP28.** `MCLK` = {J11.3, U1.34 `GPIO28_ADC2`}. Firmware/PIO must generate
   256·fs there; ES8388 slave mode auto‑detects the ratio → **no crystal on module.** ✅ resolved.
4. **Mic → single‑ended, AC‑couple on module.** `MIC_IN` = {J12.3, J15.3}; `J15 MIC_MODULE` is a
   **powered 3‑pin module** (VCC/GND/signal), so it outputs a biased/buffered signal. Module
   AC‑couples it (1 µF) into LIN1/RIN1; unused input tied to VMID. ✅ resolved.

**New finding (grounding):** `AGND` and `GND` are **separate nets** on the mainboard, bridged only
through plug‑in modules. The codec module must be the AGND↔GND **star point** at the QFN EP — see §6
(and the amp‑module ground‑loop note).

Full I²S/I²C GPIO map (netlist‑verified): DIN=GP17, ASDOUT/I2S_SDIN=GP16, BCK=GP18, LRCK=GP19,
MCLK=GP28, SDA=GP14, SCL=GP15.

---

## 8. Suggested build sequence

1. ~~Confirm Open Questions~~ — done (§7). Only residual: does the MAX17048 fuel‑gauge module carry
   its own I²C pull‑ups (harmless either way at 4.7 kΩ).
2. New KiCad project `kicad_es8388_module/`. Import `J11`/`J12` footprints + relative placement from
   `kicad_advance`.
3. Draw schematic from §2/§4 tables; run ERC.
4. Place QFN central, passives by domain, headers on the mating edge; pour grounds; DRC.
5. 3D‑overlay the module against the mainboard to verify header alignment + no component collision
   with mainboard parts in the stack‑up gap.
6. Generate JLCPCB fab + assembly outputs (the repo already has a fabrication‑toolkit config to model on).

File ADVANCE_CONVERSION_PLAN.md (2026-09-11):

# Plan: Converting the Alt-PCB into a picoTracker "Advance" Equivalent

*Drafted 2026-09-10, based on the alt-PCB `revised-pcb` branch, the public
[xiphonics/picoTracker](https://github.com/xiphonics/picoTracker) firmware
(local clone @ `98a96af`, 2026-08-14), and public Advance product info.*

> **Decisions locked 2026-09-10:**
> - MCU module: **Pimoroni Pico LiPo 2 (non-XL, PIM775)** — drop-in for the
>   existing Pico footprint. Pin budget closes by converting the 9 keys to a
>   **3×3 diode matrix** (see §4). (The XL was considered for its extra
>   GPIO but rejected to keep U1 a drop-in swap.)
> - Display: **keep the existing ILI9341 3.2" 320×240** — avoids driver,
>   font, and mechanical rework (an ST7796S 4.0" upgrade was evaluated and
>   parked; see §6).

## 1. Reality check: what the Advance is, and what is (not) public

The picoTracker Advance (launched Nov 2025) is a **commercial, closed-hardware
product**. What's publicly known:

| Spec | Advance |
| --- | --- |
| Display | 4" HiDPI **720×720** |
| Processor | "Powerful ARM processor" — exact MCU never published |
| Sample memory | **48 MB** |
| Audio out | Headphone/line out + internal speaker |
| Audio in | **Line input + internal microphone** (sampling/recording) |
| MIDI | TRS **and USB** MIDI in/out |
| Channels | 8 stereo channels |
| Storage | microSD |
| Power | USB-C charging, ~6 h battery, accurate battery metering |
| Size | 143×78×15 mm, 233 g |

Crucially, from examining the firmware repo:

- The public repo contains **only the RP2040 board adapter**
  (`sources/Adapters/picoTracker/`). There is no `advance` adapter on any
  public branch — the Advance's board-support code is private.
- The **application layer is shared and public** (BSD-3-Clause): recording
  (`RecordStreamer`, `record.h` with `LineIn`/`Mic`/`USBIn` sources — dummy
  stubs on pico), 8-channel playback, battery metering hooks, USB MIDI, etc.
  The hooks for Advance features exist; the drivers don't.
- Supported displays are **ILI9341 / ST7789, 320×240 character-cell UI** only.
- Only `PICO_PLATFORM=rp2040` build presets exist today (the bundled FreeRTOS
  does ship RP2350 ports, so an RP2350 target is plausible).

**Conclusion:** a literal clone (720×720 screen, 48 MB, unknown MCU) is a
from-scratch product design plus a firmware port with no reference code — not
a "conversion." What *is* achievable as a conversion is **functional parity**:
sampling/line-in/mic, headphone out, big sample memory, 8 solid channels,
USB+TRS MIDI, good battery metering — on the open firmware. Call it
**"Advance-lite."** That is what this plan targets.

## 2. Gap analysis: alt-PCB today vs Advance

| Feature | Alt-PCB today | Advance | Gap |
| --- | --- | --- | --- |
| MCU | RP2040 (Pimoroni Pico LiPo 16MB) | unknown ARM | ⚠ upgrade |
| Sample RAM | 264 KB SRAM (+ `LOAD_IN_FLASH`) | 48 MB | ⚠ **biggest gap** |
| Display | 3.2" ILI9341 320×240 SPI | 4" 720×720 | kept as-is by decision (upgrades parked, §6) |
| Audio out | PCM5102 I2S DAC (line-level) → MAX98306 amp → speakers | HP/line out + speaker | ~ partial (no HP driver / jack) |
| Audio in | **none** (PCM5102 is DAC-only) | line-in + mic | ⚠ needs full codec |
| MIDI TRS | in/out, 6N138 opto, A/B jumpers | in/out | ✅ done |
| USB MIDI | supported by firmware via USB-C | in/out | ✅ done |
| SD | SDIO on GP2–7 (J8) | microSD | ✅ done |
| Keys | 9 keys, same layout as Advance keymap | compatible per DEV.md | ✅ done |
| Battery | LiPo + charger on module, GP29 voltage divider | accurate metering | ~ add fuel gauge |
| Speaker | 2× micro speaker + kill switch | 1 speaker | ✅ done |

## 3. Target spec ("Advance-lite")

- **MCU module (decided): Pimoroni Pico LiPo 2 (PIM775)** — RP2350B, 16 MB
  flash, 8 MB PSRAM, USB-C, MCP73831 charger + XB6096 protection, Qw/ST I2C
  connector, **standard Pico footprint → U1 is a drop-in swap**. Board
  housekeeping lives on non-exposed high GPIOs (BOOT GP45, VBAT sense GP43,
  PSRAM CS internal), so all 26 exposed GPIO (GP0–22, GP26–28) are free for
  the design. Battery voltage remains readable with zero external pins via
  GP43. Trade-off accepted: the exposed pin budget closes exactly and only
  via the key-matrix conversion (§4) — no headroom remains.
- **Display (decided): keep the ILI9341 3.2" 320×240** — fully supported by
  stock firmware (`USE_LCD=LCD_ILI9341`), no driver/font work, no board
  outline or back-panel changes. Larger-screen options stay parked in §6.
- **Full audio codec** replacing the GY-PCM5102 module: stereo DAC + stereo
  ADC + mic input + headphone driver. Candidates:
  - **TLV320AIC3204/3254** (TI): ADC+DAC+PGA mic in+HP driver in one chip, I2C
    control — closest to one-chip Advance-like audio. SMD only.
  - **ES8388 module** (cheap AliExpress/LCSC): ADC+DAC+HP amp, I2C — good
    module-style fit matching this board's THT/module philosophy.
  - **PCM3060** (ADC+DAC, no HP amp/mic bias — pair with MAX9724/TPA6132 HP
    amp and a MEMS mic preamp) — simplest I2S, more parts.
- **Headphone/line-out 3.5 mm jack** with switch contact → mute speaker amp
  (`SD` pin on MAX98306) when plugged.
- **Analog MEMS mic** (e.g. SPW2430 module or ICS-40180) into codec mic input,
  port hole in back panel.
- **I2C fuel gauge** (MAX17048) for accurate battery %, on the same I2C bus as
  the codec (or the Pico LiPo 2's Qw/ST connector).
- Keep: SDIO SD, TRS MIDI circuit, 9-key layout, MAX98306 + speakers, kill
  switch, sandwich-PCB enclosure concept.

## 4. Pin budget (closes exactly — the key matrix is what makes it work)

The Pico LiPo 2 exposes the standard 26 Pico GPIO (GP0–22, GP26–28), and
today's map consumes **all 26**: MIDI GP0/1 · SDIO GP2–7 · keys GP8–16 ·
I2S out GP17–19 · display CS/DC/RST GP20–22 · display SCK/MOSI/MISO
GP26–28. (Old GP23 backlight-PWM and GP29 VBATT entries are module-internal
concerns; on the LiPo 2 battery sense is internal GP43.)

**Recovered pins (4):**

| Change | Pins freed |
| --- | --- |
| 9 direct-wired keys → **3×3 matrix** (3 rows + 3 cols on GP8–13, one 1N4148 per switch) | GP14–16 (3) |
| Display MISO unused (driver is write-only) → leave unrouted | GP28 (1) |

**Spent on new signals (4):**

| New signal | Pin |
| --- | --- |
| I2S data-in (BCLK/LRCLK shared with the DAC clocks) | GP16 |
| I2C SDA/SCL (codec ctrl + MAX17048) | GP14/15 |
| Codec MCLK (PIO-generated 256·fs) | GP28 |

**MCLK instead of jack detect** (decided during schematic capture): nearly
every affordable codec module (ES8388 etc.) requires an MCLK the PIO I2S
engine doesn't currently produce, so GP28 goes to MCLK — a codec that PLLs
from BCLK (TLV320AIC3204) can simply leave the pin NC. Headphone jack
detect and speaker auto-mute were dropped with it: the PJ311 jack footprint
this board standardizes on has no switch contact anyway, and the existing
manual kill switch (J9) already covers speaker muting. Result: **26/26
used, zero spare** — any future feature reopens this fight (the accepted
price of the non-XL module).

Matrix notes: diodes are mandatory — tracker key combos mean 3+ simultaneous
presses, and a diode per switch (9× 1N4148, same part as D1) makes the
matrix ghost-free. GP assignments above are indicative; final choice should
respect RP2350 I2C/PIO pin-function tables during schematic capture.

## 5. Workstreams

### A. PCB rev (KiCad) — the part that lives in this repo
1. New branch off `revised-pcb`. U1 is a **drop-in swap** (Pico LiPo 2 uses
   the standard Pico footprint) — verify USB-C connector overhang and the
   JST battery connector position against the sandwich clearances.
2. **Rewire the key block as a 3×3 matrix**: rows/cols on GP8–13, one
   1N4148 per switch (9×, same part as D1 — cheap THT). Key positions and
   caps unchanged; only the copper changes.
3. Display J7, board outline, display window, key positions, and MIDI jacks
   stay unchanged — the existing back panel STL survives with only mic-hole
   + HP-jack edits.
4. Replace U3 (PCM5102 6-pin header) with codec module/IC footprint; route
   I2S in/out + I2C; add mic bias/input and HP jack with detect switch.
5. Add 3.5 mm headphone jack (PJ-320 style to match existing MIDI jacks),
   MEMS mic footprint + acoustic port, MAX17048 + sense wiring to battery.
6. Update `pico_tracker.csv` BOM + README table; re-run ERC/DRC; regenerate
   gerbers.

### B. Firmware — the long pole (fork of xiphonics/picoTracker)
1. **RP2350 build target**: add `PICO_PLATFORM=rp2350` preset with the
   Pico LiPo 2 board file (`PICO_BOARD`); FreeRTOS RP2350 port already
   vendored; fix whatever `-Werror` fallout appears. (Small–medium.)
1b. **Key-matrix scan driver**: replace the 9-GPIO direct reads in
   `picoTrackerEventManager` with a 3×3 scan (drive one column low at a
   time, read 3 rows; full sweep every tick). With per-switch diodes, all
   9 keys are independently readable in any combination — ALT-holds and
   multi-key tracker combos behave identically to direct wiring; scanning
   at ≥1 kHz keeps added latency under 1 ms. Keep debounce and event
   semantics unchanged (upstream requires identical key behavior).
   (Small–medium.)
2. **PSRAM sample memory**: init RP2350 QMI PSRAM (8 MB), point the sample
   pool at it, replace/augment `LOAD_IN_FLASH`. This is the change that makes
   "more than a toy amount of sample memory" real. (Medium.)
3. **Codec driver**: I2C register setup + PIO I2S full-duplex (new PIO
   program for RX; TX program exists in `audio_i2s.pio`), plus a PIO/clock
   divider generating 256·fs MCLK on GP28 for codecs that need it (pick a
   sys-clock that divides to exact audio rates). Implement the real
   `record.h` API (`SetInputSource`, mic gain, levels) — the app-side
   `RecordStreamer` UI already exists upstream. (Medium–hard; the core new
   engineering.)
4. **Fuel gauge driver** feeding the existing battery-gauge view; upstream
   already has a TODO noting the pico's approximate metering
   (`View.cpp:415`). (Small.)
5. **8-channel perf validation** on RP2350 (M33 + FPU @150 MHz+, dual core).
   Upstream README says the RP2040 struggles with 8 channels; RP2350 should
   close most of that, but measure. (Test/tune.)
6. **Engage upstream early**: DEV.md invites per-case GitHub issues; keys,
   screenmap, and file formats must stay Advance-compatible. An RP2350 +
   codec "community hardware v3" may be upstreamable, or can live in
   `picoTracker-playground`. License is BSD-3 — no obstacles.

### C. Enclosure
- Back panel STL: mic port + HP jack cutout only; verify the ~11 mm internal
  depth still clears the codec module (prefer low-profile/SMD parts if not).

### D. Validation
- Bring-up checklist: power/charge → display → SD → keys → MIDI loopback →
  DAC playback → HP out → recording from line-in → mic → battery gauge.
- Burn-in: 8-channel project playback for CPU headroom; 6 h battery test.

## 5½. Implementation status: `kicad_advance/`

`kicad_advance/` is a copy of `kicad/` carrying the schematic + PCB updates:

- **Schematic — done** (ERC: 0 errors): key matrix (COL0-2 on GP11-13, ROW0-2
  on GP8-10, D2–D10), codec headers J11 `CODEC_DIG` (3V3/GND/MCLK/BCK/LRCK/
  DIN/DOUT/SDA/SCL) + J12 `CODEC_ANA` (LINE_L/R, MIC_IN, L_AMP/R_AMP, AGND),
  J13 line-in + J14 phones jacks, J15 mic module, J16 fuel-gauge header on
  I2C, MCLK on GP28, PCM5102 (old U3) removed. Amp input now taps the codec
  HP outs (nets `L_AMP`/`R_AMP` unchanged at J10).
- **PCB — placed and routed**: all 9 diodes sit on **B.Cu (back)** among the
  switch rows (cathode toward its ROW), codec headers J11/J12, jacks J13/J14,
  mic J15 and fuel-gauge J16 are placed on-board along the right, and all 47
  new-net connections (COL/ROW matrix, I2S BCK/LRCK/DIN/data-in, MCLK, I2C
  SDA/SCL, MIC_IN, L_AMP/R_AMP/AGND, and header VCC/GND) are auto-routed on
  a 0.2 mm grid (0.25 mm tracks, 0.25 mm clearance), with GND-island stitch
  vias and zones refilled. Total DRC count *dropped* 528 → 343 (the refill
  cleaned up stale-fill shorts in the original pour).
- **Verified clean on the new nets**: the only DRC item touching a new net is
  an I2S_SDIN↔VCC pad-proximity flag at U1.21/R4.2 that is **already present
  in the pre-routing board** (stranded R4.2 VCC pad in the dense MIDI/power
  cluster) — not introduced by this routing. Everything else new is
  cosmetic (silkscreen ref-designator clipping on the back-side parts).
- **Known pre-existing (not from this work)**: the original hand-routed
  MIDI/opto/power cluster around U1's south edge carries ~70 strict-DRC
  "shorts" (sub-0.2 mm hand spacing) and a stranded R4.2 VCC pad; these
  predate the conversion and were left untouched.
- **Conventions kept**: J13/J14 PJ311 pads are left unnetted like the
  existing MIDI jacks (symbol S/R/T vs pads 1–6) — hand-wire as before.

Remaining PCB polish (optional, human pass in KiCad): tidy the auto-router's
B.Cu detours, add GND thermal spokes on a few U1 pads flagged as 1-spoke,
and resolve the pre-existing MIDI-cluster strict-DRC shorts if a clean DRC
is wanted before fab.

## 6. Explicitly out of scope (and why)

- **720×720 HiDPI display**: no RP-family chip can drive it (no LTDC/MIPI-DSI,
  and the open firmware's renderer is a character-cell engine). Doing this
  means a new MCU class (STM32H7/i.MX RT + SDRAM + RGB/DSI panel) and a
  ground-up firmware port with no public reference — that's designing a
  second Advance, not converting this board.
- **Display upgrades generally (parked by decision)**: the best candidate if
  this is ever revisited is the **ST7796S 4.0" 480×320 SPI** — RGB565 over
  SPI like the ILI9341, 1:1 rewire of J7, needing a new init sequence, 15×13
  px `chargfx` cells, a redrawn ~12×12 font, and a larger board
  outline/back panel. Deferred to keep this rev's scope on audio + memory.
- **480×480 square RGB panel (Presto-style)**: considered and parked. Proven
  on RP2350B (Pimoroni Presto drives an ST7701 over parallel RGB via
  PIO+DMA+PSRAM framebuffer on core1), but costs ~20 GPIO, a core, and a
  much bigger driver effort than the chosen SPI panel. Revisit only after
  the codec/PSRAM work lands, if ever.
- **48 MB**: 8 MB PSRAM is the practical RP2350 ceiling per QMI CS; it's a
  30× upgrade over today and covers most real use.
- Matching the Advance's industrial design/size.

## 7. Effort & cost (rough)

| Item | Estimate |
| --- | --- |
| PCB rev + layout + BOM | ~2–4 evenings (U1 drop-in; key-matrix rewiring + audio section are the changes) |
| Fab + parts per unit | board ~$5–15; Pico LiPo 2 ~$14; codec $2–10; gauge ~$2; jack/mic ~$3; 9× 1N4148 pennies — **≈ $55–75/unit** with existing display/keys/amp |
| Firmware: RP2350 target | days |
| Firmware: key-matrix scan driver | days |
| Firmware: PSRAM samples | ~1 week part-time |
| Firmware: codec + recording | 1–3 weeks part-time (long pole) |
| Firmware: fuel gauge, polish | days |

## 8. Open questions / risks

1. **Pico LiPo 2 (PIM775) details** — from the schematic, confirm: PSRAM CS
   is fully internal; GP43 battery-sense divider ratio (for a firmware
   fallback read); which GPIO the Qw/ST connector shares (if it lands on
   pins this design uses, the connector is simply unusable — fine, the
   I2C bus is on GP14/15 anyway); USB-C/JST mechanical overhang vs the
   sandwich enclosure.
2. **Codec choice** — module (ES8388, easy, matches THT philosophy) vs chip
   (AIC3204, cleaner, SMD reflow). Decide based on how SMD-averse this board
   wants to stay (it just moved *to* THT).
3. **PIO budget** — SDIO uses pio1, audio TX uses pio0; RX I2S needs a free
   state machine (pio0 has 3 spare; RP2350 adds pio2 — fine, but verify DMA
   channel allocation).
4. **Upstream appetite** — whether xiphonics accepts an RP2350/codec target
   or it lives as a community fork determines long-term maintenance cost.
5. **Advance feature drift** — Advance firmware is versioned separately;
   "equivalence" is a moving target. Anchor on: sampling, 8 channels, HP out,
   USB+TRS MIDI, real battery meter.

## Sources

- [xiphonics picoTracker product page](https://xiphonics.com/products/picotracker)
- [xiphonics/picoTracker firmware](https://github.com/xiphonics/picoTracker) (local clone examined: `sources/Adapters/picoTracker/platform/gpio.h`, `audio/record.h`, `docs/DEV.md`, `CMakePresets.json`)
- [picoTracker Advance manual](https://manual.xiphonics.com/advance/introduction.html)
- [Elektronauts Advance thread](https://www.elektronauts.com/t/xiphonics-picotracker-advance/243649)
- [Pimoroni Pico LiPo 2](https://shop.pimoroni.com/en-us/products/pimoroni-pico-lipo-2) · [Pico LiPo 2 XL W](https://shop.pimoroni.com/en-us/products/pimoroni-pico-lipo-2-xl-w)
- [Pimoroni Presto](https://shop.pimoroni.com/en-us/products/presto) + [ST7701 driver internals](https://deepwiki.com/pimoroni/presto/2.2-st7701-display-driver) — existence proof for the parked 480×480 RGB option

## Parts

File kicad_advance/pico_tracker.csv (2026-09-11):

Reference(s) | Value | Footprint | Qty
D1-D10 | 1n4148 | Diode_THT:D_DO-35_SOD27_P7.62mm_Horizontal | 10
J1 | MIDI_OUT | Connector_Audio:Jack_3.5mm_PJ311_Horizontal | 1
J2 | MIDI_IN | Connector_Audio:Jack_3.5mm_PJ311_Horizontal | 1
J3 | MIDI_IN_A_B_VCC | Connector_PinHeader_2.54mm:PinHeader_1x03_P2.54mm_Vertical | 1
J4 | MIDI_IN_A_B_DATA | Connector_PinHeader_2.54mm:PinHeader_1x03_P2.54mm_Vertical | 1
J5 | MIDI_OUT_A_B_VCC | Connector_PinHeader_2.54mm:PinHeader_1x03_P2.54mm_Vertical | 1
J6 | MIDI_OUT_A_B_DATA | Connector_PinHeader_2.54mm:PinHeader_1x03_P2.54mm_Vertical | 1
J7 | DISPLAY | Connector_PinHeader_2.54mm:PinHeader_1x08_P2.54mm_Vertical | 1
J8 | SDCARD | Connector_PinHeader_2.54mm:PinHeader_1x09_P2.54mm_Vertical | 1
J9 | KILL_SWITCH | Button_Switch_THT:SW_CK_JS202011AQN_DPDT_Angled | 1
J10 | DclassAMP | Connector_PinHeader_2.54mm:PinHeader_1x09_P2.54mm_Vertical | 1
J11 | CODEC_DIG | Connector_PinHeader_2.54mm:PinHeader_1x09_P2.54mm_Vertical | 1
J12 | CODEC_ANA | Connector_PinHeader_2.54mm:PinHeader_1x06_P2.54mm_Vertical | 1
J13 | LINE_IN | Connector_Audio:Jack_3.5mm_PJ311_Horizontal | 1
J14 | PHONES | Connector_Audio:Jack_3.5mm_PJ311_Horizontal | 1
J15 | MIC_MODULE | Connector_PinHeader_2.54mm:PinHeader_1x03_P2.54mm_Vertical | 1
J16 | FUEL_GAUGE | Connector_PinHeader_2.54mm:PinHeader_1x06_P2.54mm_Vertical | 1
R1,R3 | 47R | Resistor_THT:R_Axial_DIN0207_L6.3mm_D2.5mm_P7.62mm_Horizontal | 2
R2 | 220R | Resistor_THT:R_Axial_DIN0207_L6.3mm_D2.5mm_P7.62mm_Horizontal | 1
R4 | 470R | Resistor_THT:R_Axial_DIN0207_L6.3mm_D2.5mm_P7.62mm_Horizontal | 1
R5 | 10k | Resistor_THT:R_Axial_DIN0207_L6.3mm_D2.5mm_P7.62mm_Horizontal | 1
SW1 | LEFT | Button_Switch_Keyboard:SW_PG1350 | 1
SW2 | DOWN | Button_Switch_Keyboard:SW_PG1350 | 1
SW3 | RIGHT | Button_Switch_Keyboard:SW_PG1350 | 1
SW4 | UP | Button_Switch_Keyboard:SW_PG1350 | 1
SW5 | RT | Button_Switch_Keyboard:SW_PG1350 | 1
SW6 | B | Button_Switch_Keyboard:SW_PG1350 | 1
SW7 | A | Button_Switch_Keyboard:SW_PG1350 | 1
SW8 | LT | Button_Switch_Keyboard:SW_PG1350 | 1
SW9 | PLAY | Button_Switch_Keyboard:SW_PG1350 | 1
U1 | Pico | RPi_Pico:RPi_Pico_SMD_TH | 1
U2 | 6N138 | Package_DIP:DIP-8_W7.62mm | 1

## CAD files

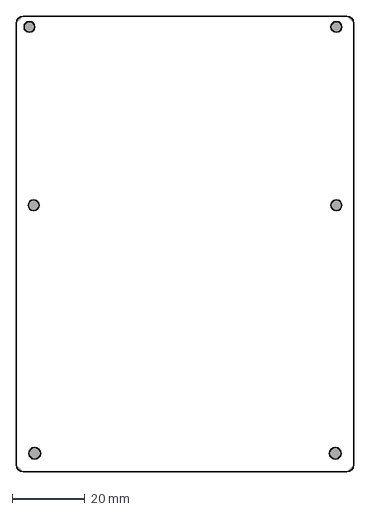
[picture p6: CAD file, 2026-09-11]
kicad_advance/pico_tracker-Edge_Cuts.dxf
92.9 x 125.4 mm

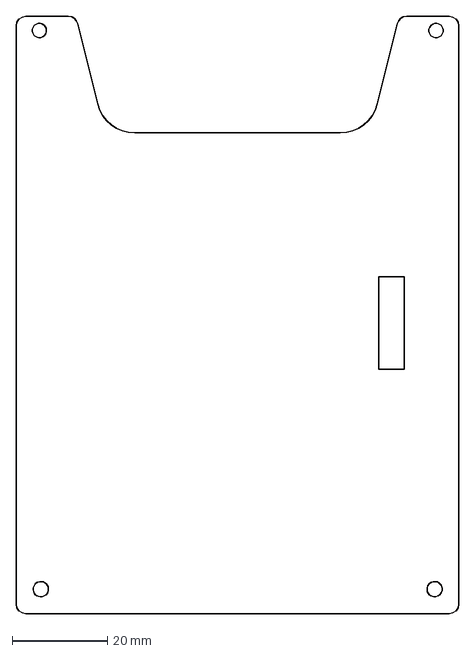
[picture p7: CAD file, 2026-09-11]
kicad_advance/pcb_tmp.dxf
92.9 x 125.4 mm

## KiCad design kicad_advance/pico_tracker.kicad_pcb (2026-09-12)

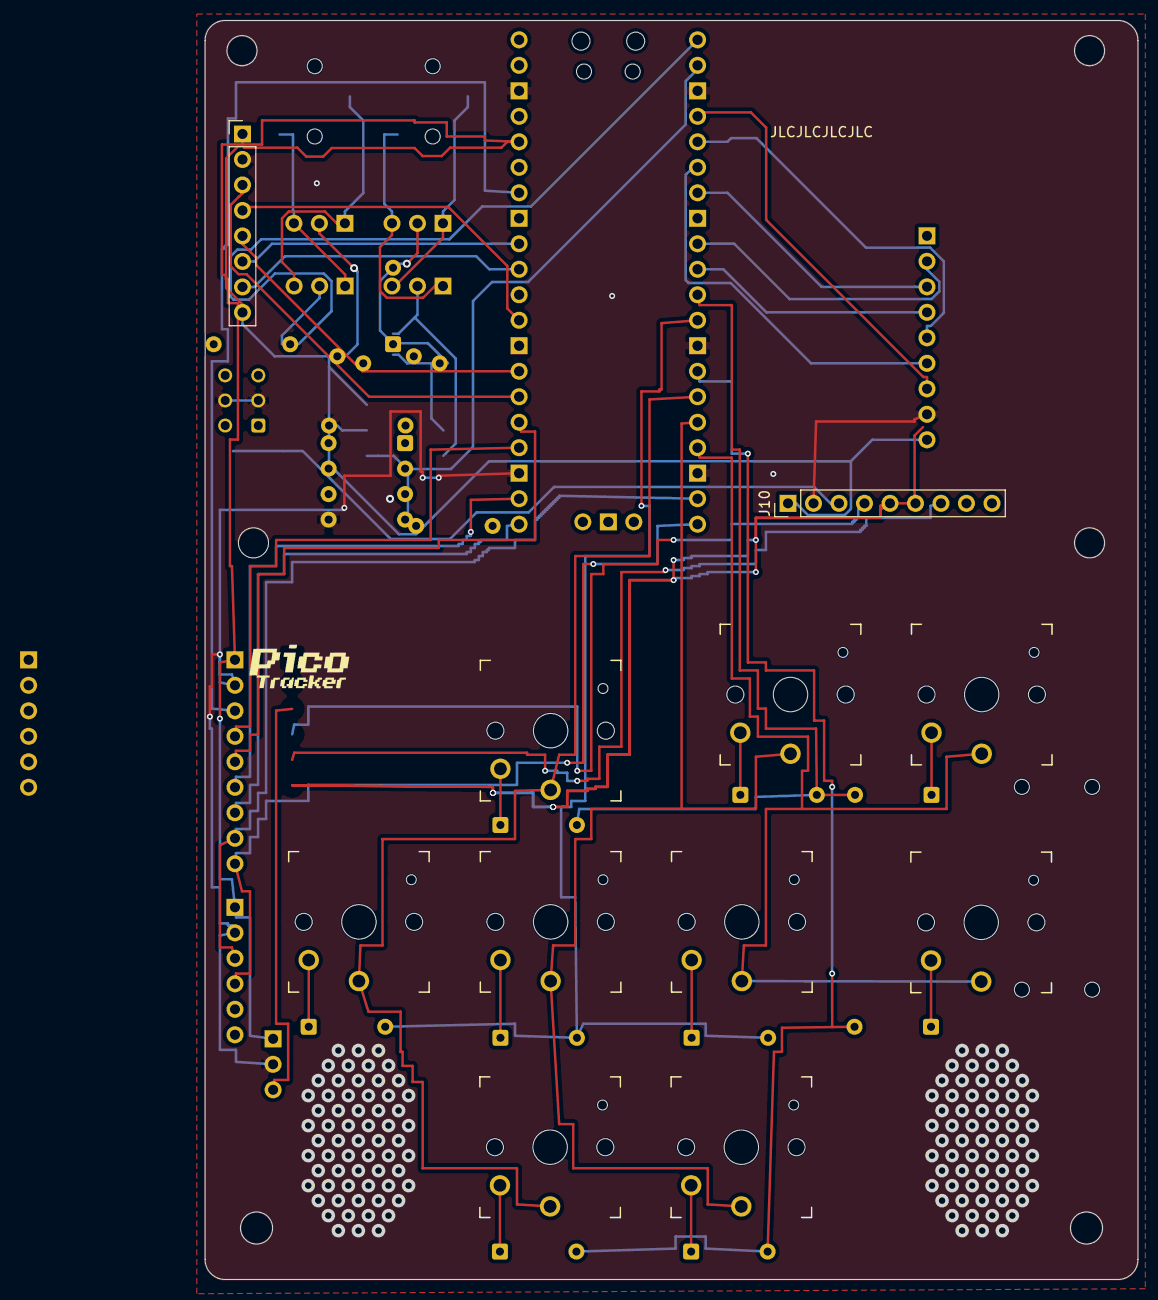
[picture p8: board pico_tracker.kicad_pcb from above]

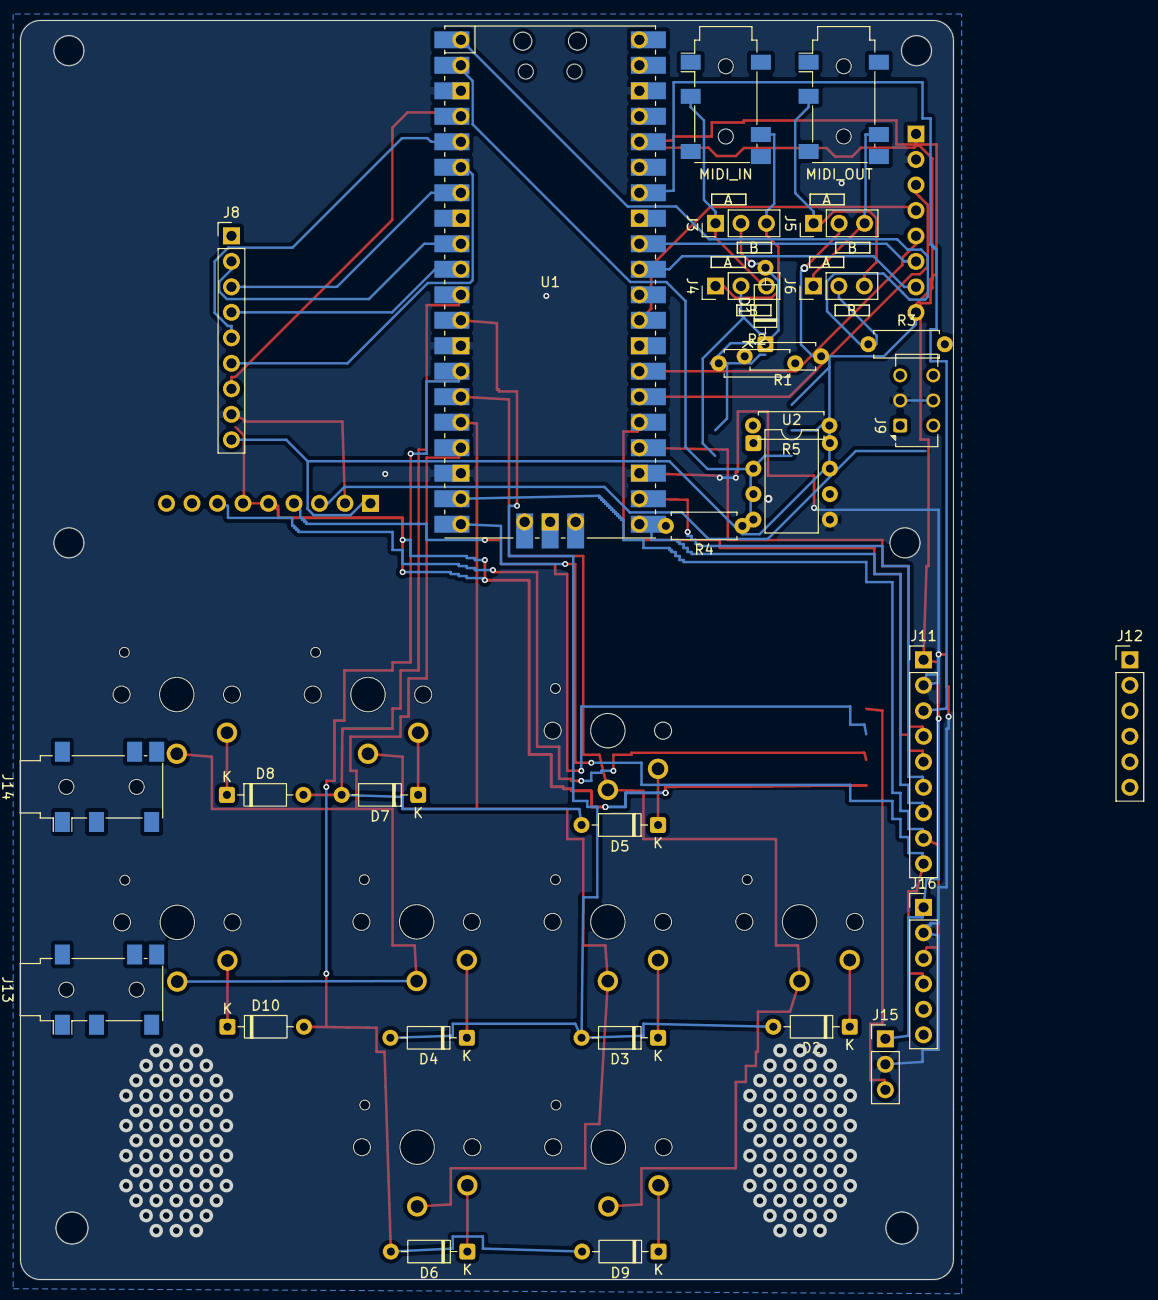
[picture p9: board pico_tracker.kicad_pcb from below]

Board: 2 copper layers, 92.9 x 125.4 mm, 43 parts (31 on the bottom side), 52 nets.

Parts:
D1, D2, D3, D4, D5, D6, D7, D8, D9, D10: 1n4148; D_DO-35_SOD27_P7.62mm_Horizontal
G1: LOGO; logo_silk
J1: MIDI_OUT; Jack_3.5mm_PJ311_Horizontal
J2: MIDI_IN; Jack_3.5mm_PJ311_Horizontal
J3: MIDI_IN_A_B_VCC; PinHeader_1x03_P2.54mm_Vertical
J4: MIDI_IN_A_B_DATA; PinHeader_1x03_P2.54mm_Vertical
J5: MIDI_OUT_A_B_VCC; PinHeader_1x03_P2.54mm_Vertical
J6: MIDI_OUT_A_B_DATA; PinHeader_1x03_P2.54mm_Vertical
J7: DISPLAY; PinHeader_1x08_P2.54mm_Vertical
J8: SDCARD; PinHeader_1x09_P2.54mm_Vertical
J9: KILL_SWITCH; SW_CK_JS202011AQN_DPDT_Angled
J10: DclassAMP; PinHeader_1x09_P2.54mm_Vertical
J11: CODEC_DIG; PinHeader_1x09_P2.54mm_Vertical
J12: CODEC_ANA; PinHeader_1x06_P2.54mm_Vertical
J13: LINE_IN; Jack_3.5mm_PJ311_Horizontal
J14: PHONES; Jack_3.5mm_PJ311_Horizontal
J15: MIC_MODULE; PinHeader_1x03_P2.54mm_Vertical
J16: FUEL_GAUGE; PinHeader_1x06_P2.54mm_Vertical
R1, R3: 47R; R_Axial_DIN0207_L6.3mm_D2.5mm_P7.62mm_Horizontal
R2: 220R; R_Axial_DIN0207_L6.3mm_D2.5mm_P7.62mm_Horizontal
R4: 470R; R_Axial_DIN0207_L6.3mm_D2.5mm_P7.62mm_Horizontal
R5: 10k; R_Axial_DIN0207_L6.3mm_D2.5mm_P7.62mm_Horizontal
SW1, SW2, SW3, SW4, SW5, SW6, SW7, SW8, SW9: SW_PG1350
U1: Pico; RPi_Pico_SMD_TH
U2: 6N138; DIP-8_W7.62mm

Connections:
AGND: J10.5, J10.6, J12.6
BCK: J11.4, U1.24 (GPIO18)
CLK: J8.7, U1.4 (GPIO2)
COL0: SW1.1, SW4.1, SW8.1, U1.15 (GPIO11)
COL1: SW2.1, SW5.1, SW6.1, U1.16 (GPIO12)
COL2: SW3.1, SW7.1, SW9.1, U1.17 (GPIO13)
D1: J8.3, U1.7 (GPIO5)
D3: J8.4, U1.10 (GPIO7)
DAT2: J8.2, U1.9 (GPIO6)
DIN: J11.6, U1.22 (GPIO17)
DP3: J7.3, U1.26 (GPIO20)
DP4: J7.4, U1.29 (GPIO22)
DP5: J7.5, U1.27 (GPIO21)
DP6: J7.6, U1.32 (GPIO27_ADC1)
DP7: J7.7, U1.31 (GPIO26_ADC0)
GND: J7.2, J8.8, J9.2, J9.5, J10.2, J11.2, J15.2, J16.2, R5.1, U1.3 (GND), U1.13 (GND), U1.18 (GND), U1.23 (GND), U1.38 (GND), U2.5
I2S_SDIN: J11.7, U1.21 (GPIO16)
KILL_SWITCH: J9.1, J9.4, J10.3
LRCK: J11.5, U1.25 (GPIO19)
L_AMP: J10.4, J12.4
MCLK: J11.3, U1.34 (GPIO28_ADC2)
MIC_IN: J12.3, J15.3
unnamed: D1.2, J4.2, U2.3
unnamed: D1.1, R2.2, U2.2
unnamed: D2.1, SW1.2
unnamed: D3.1, SW2.2
unnamed: D4.1, SW3.2
unnamed: D5.1, SW4.2
unnamed: D6.1, SW5.2
unnamed: D7.1, SW6.2
unnamed: D8.1, SW7.2
unnamed: D9.1, SW8.2
unnamed: D10.1, SW9.2
unnamed: J3.1, J4.3
unnamed: J3.2, R2.1
unnamed: J3.3, J4.1
unnamed: J5.1, J6.3
unnamed: J5.2, R1.2
unnamed: J5.3, J6.1
unnamed: J6.2, R3.2
unnamed: R5.2, U2.7
ROW0: D5.2, D7.2, D8.2, U1.11 (GPIO8)
ROW1: D2.2, D3.2, D4.2, U1.12 (GPIO9)
ROW2: D6.2, D9.2, D10.2, U1.14 (GPIO10)
RX: R4.1, U1.2 (GPIO1), U2.6
R_AMP: J10.7, J12.5
SCL: J11.9, J16.4, U1.20 (GPIO15)
SDA: J11.8, J16.3, U1.19 (GPIO14)
SI: J8.5, U1.5 (GPIO3)
SO: J8.6, U1.6 (GPIO4)
TX: R3.1, U1.1 (GPIO0)
VCC: J7.1, J7.8, J8.9, J10.1, J11.1, J15.1, J16.1, R1.1, R4.2, U1.36 (3V3), U2.8

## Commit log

2026-09-11 switch to tht, update parts links with estimated prices
    [pico_tracker.csv, pico_tracker.kicad_pcb, pico_tracker.kicad_sch]
2026-09-11 fix alignment holes
    [pico_tracker_back.kicad_pcb]
2026-09-11 Add Advance-equivalent conversion plan
    Documents the plan to bring the alt-PCB to functional parity with the
    picoTracker Advance: Pico LiPo 2 (RP2350B, 8MB PSRAM), full audio codec
    with line-in/mic/headphone, MAX17048 fuel gauge, and a 3x3 diode key
    matrix to close the pin budget. Display stays ILI9341 320x240.
2026-09-11 Add kicad_advance: schematic+PCB for the Advance-lite conversion
    Copy of kicad/ updated to the conversion plan:
    Schematic (ERC clean):
    - 9 direct-wired keys become a 3x3 diode matrix: COL0-2 on GP11-13,
    ROW0-2 on GP8-10, one 1N4148 per switch (D2-D10)
    - GP14/15 become I2C (SDA/SCL), GP16 I2S data-in, GP28 codec MCLK
    - PCM5102 module (U3) replaced by codec module headers J11 (digital:
    MCLK/BCK/LRCK/DIN/DOUT/I2C) and J12 (analog: line-in L/R, mic in,
    HP out feeding the amp via existing L_AMP/R_AMP nets)
    - New: J13 line-in jack, J14 phones jack, J15 mic module header,
    J16 fuel-gauge header (MAX17048 breakout) on the I2C bus
    - Speaker auto-mute/jack-detect dropped: PJ311 has no switch c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
    [pcb_tmp.dxf, pico_tracker-Edge_Cuts.dxf, pico_tracker.csv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]
2026-09-11 Place and route the Advance-lite footprints in kicad_advance
    Placement:
    - All 9 matrix diodes (D2-D10) on B.Cu (back side), tucked among the
    switch rows with each cathode facing its ROW net
    - Codec headers J11/J12, line-in J13, phones J14, mic J15, and
    fuel-gauge J16 placed on-board along the right edge
    Routing:
    - All 47 new-net connections auto-routed on a 0.2mm grid (0.25mm
    tracks, 0.25mm clearance, vias where a layer change is needed):
    COL0-2/ROW0-2 key matrix, I2S BCK/LRCK/DIN/data-in, codec MCLK,
    I2C SDA/SCL, MIC_IN, HP-amp L_AMP/R_AMP/AGND, header VCC/GND
    - GND islands stitched to the pour; zones refilled
    Verification:
    - Total DRC count drops 528 -> 343 (refill cleared stal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
    [pico_tracker.kicad_pcb]
2026-09-11 Clean up Advance schematic: remove top image, fix label overlaps
    - Remove the large embedded bitmap that floated above the top sheet edge
    (~425KB base64 blob at y=-21.59)
    - Relocate the codec/jack/mic/fuel-gauge block (J11-J16) out of the
    title-block corner into the open center band, with each part's
    reference designator moved alongside its symbol
    - Move the diode 1n4148 values below their symbols so they no longer
    clip the ROW labels
    - Re-lay the 9-key diode matrix as a clean 3x3 grid (COL x ROW) with
    generous spacing instead of two crammed rows
    Purely cosmetic: netlist diff vs prior commit confirms all 75 nets and
    their connections are identical; ERC still passes with 0 errors.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
    [pico_tracker.kicad_sch]
2026-09-11 Remove stray REF1 amp header and re-route amp nets
    REF1 was an orphan footprint (a 1x9 SMD pin header on the back, upper
    right) with no schematic symbol - a leftover in the original board that
    tapped the class-D amp nets (L_AMP/R_AMP/AGND) in parallel with J10.
    - Delete the REF1 footprint and its now-dangling feed traces
    - Re-route L_AMP (J10.4<->J12.4), R_AMP (J10.7<->J12.5) and AGND
    (J12.6<->J10.5) among their real pads so nothing is left floating
    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
    [pico_tracker.kicad_pcb]
2026-09-12 Advance-lite: widen codec header J12 to 1x9, reposition for ES8388 module mate
    - J12 CODEC_ANA 6->9 pins (schematic); pins 7-9 carry the module line-out
    (LINEOUT_L/R/GND), unconnected on the mainboard.
    - Move J12 on the PCB to (84.24, 91.84) so J11/J12 are 20.56mm apart, matching
    the ES8388 breakout module's two 1x9 edge headers (Digital-right/Analog-left).
    - Add ES8388 module plan + schematic walkthrough docs.
    Note: run Update PCB from Schematic to finalize J12's 6->9 footprint swap.
    [pico_tracker.kicad_pcb, pico_tracker.kicad_sch]
2026-09-23 Ignore editor history, KiCad backups, and fabrication output
